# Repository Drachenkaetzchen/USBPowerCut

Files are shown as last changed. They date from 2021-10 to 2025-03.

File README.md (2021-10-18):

# USB Power Cut

A small PCB to control power to a USB device. I've designed this in order to be able to cut power to a
[HDMI display](https://www.aliexpress.com/item/32889893278.html) when it's not in use, for example, via a Raspberry Pi.

# Specifications

- MicroUSB input
- USB Type A output
- Maximum permissible USB current draw: 1A
- JST XH to control the power. Control voltage 3.3V or 5V.
- Active power consumption 35mA (only when switched on)
- USB data lines are passed through

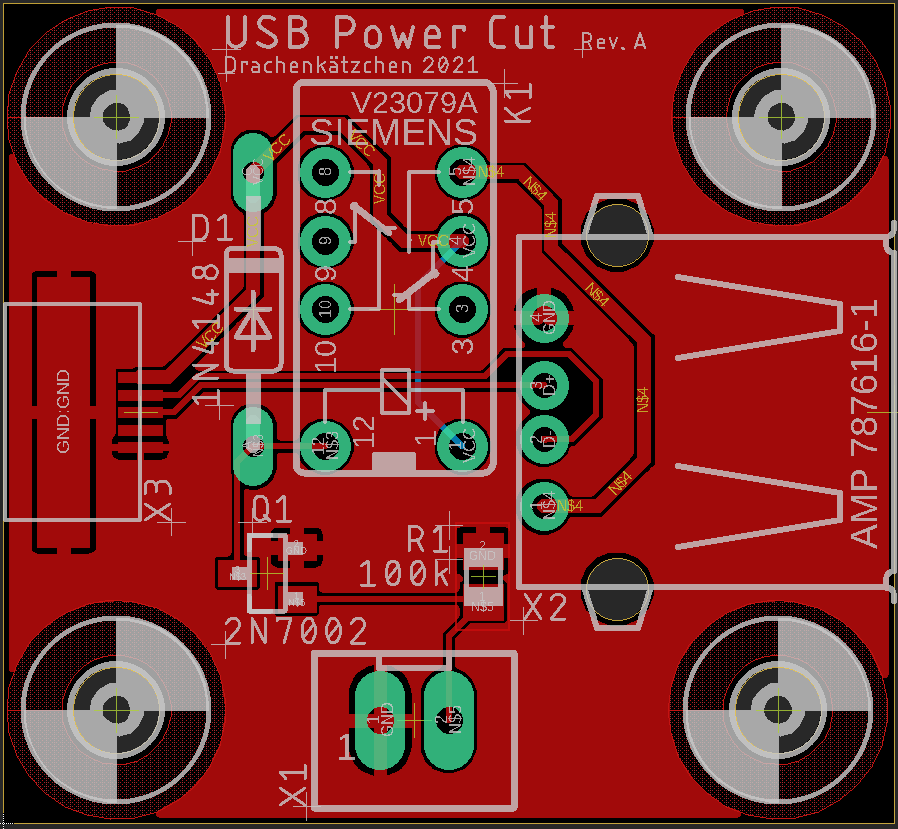
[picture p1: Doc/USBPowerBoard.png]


# Known Issues

- One mounting hole is offset to the right by 0.5mm, the DIN mounting adapter is adjusted for that.

# BOM

| Designator| Part
| ---|---
| D1 | 1N4148 DO35-10 
| K1 | V23079-A1011-B301 
| Q1 | 2N7002 SOT23 
| R1 | 100k 0805 
| X1 | JST XH 2 pin
| X2 | AMP 787616-1 
| X3 | 10104110-0001LF 

# FAQ

**Why a relay?**

I didn't have any P-channel mosfets in stock, but plenty of those small relays, so that's why I based my design around
them. I rather use components I have in stock than to order new ones.

N-channel mosfets shouldn't be used to control USB power due to possible leakage over the data lines.

**Why not use the RPI4 USB power control functionality?**

On a Raspberry Pi 4, this cuts power to all USB ports. In my case, I only want the display to be turned off. All other
ports should remain on.

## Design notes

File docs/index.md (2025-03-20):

# USB Power Cut Beta 2

A small device which can disconnect power to an attached USB device. The data pins are connected permanently.

## Example use cases
- Disconnect the Beacon surface scanner if not in use
- Turn off a screen powered by USB

## Usage
- Connect GND to any V-/GND point on your mainboard (NOT Fan-, that is not GND/V- but a switched GND!)
- Connect CTL to any pin that can pull CTL low, examples:
  - Fan- on any fan output
  - GPIO pins which are directly connected to STM32 MCUs (RP2040 MCUs cannot handle direct connection, Fan- on RP2040 MCUs is fine)
  - Toggle Switch between CTL and GND 

## Technical Details
- CTL is pulled up to 5V via a 10k resistor (hence the RP2040 MCU limitation)
- Uses a dedicated USB power controller to safely switch power (AP2111SG)
- Maximum current capability: 2A

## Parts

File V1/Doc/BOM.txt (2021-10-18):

Partlist

Exported from USBPowerCut.brd at 18/10/2021 12:52

EAGLE Version 9.6.2 Copyright (c) 1988-2020 Autodesk, Inc.

Assembly variant: 

Part     Value                  Package                    Library                                        Position (mil)        Orientation

D1       1N4148                 DO35-10                    diode                                          (365 750)             R270
K1       V23079-A1011-B301      V23079A                    Siemens-Rel                                    (570 750)             R90
Q1       2N7002                 SOT23                      nxp_60_1_1                                     (385 365)             R90
R1       100k                   R0805                      rcl                                            (700 360)             R90
X1       JST-XH-02-PIN-LONG-PAD JST-XH-02-PACKAGE-LONG-PAD Rembrandt Electronics - JST XH Connectors v1-0 (600 150)             R0
X2       AMP 787616-1           USB                        con-amp                                        (1300 600)            R90
X3       10104110-0001LF        MICRO_USB                  10104110-0001LF                                (200 600)             R270

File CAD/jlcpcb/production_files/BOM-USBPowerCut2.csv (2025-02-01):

Comment | Designator | Footprint | LCSC | Quantity
Conn_01x02_Pin | J2 | JST_PH_B2B-PH-K_1x02_P2.00mm_Vertical | C131337 | 1
100n | C1 | C_0603_1608Metric | C14663 | 1
AP2111SG-13 | IC1 | SOIC127P600X175-8N | C151559 | 1
10uF | C2 | C_0603_1608Metric | C19702 | 1
USB_A | J3 | USB_A_CONNFLY_DS1095-WNR0 | C19944603 | 1
1M | R1,R5 | R_0603_1608Metric | C22935 | 2
5.1k | R2,R3 | R_0603_1608Metric | C23186 | 2
10k | R4 | R_0603_1608Metric | C25804 | 1
USB_C_Receptacle_USB2.0_16P | J1 | USB_C_Receptacle_HRO_TYPE-C-31-M-12 | C2988369 | 1

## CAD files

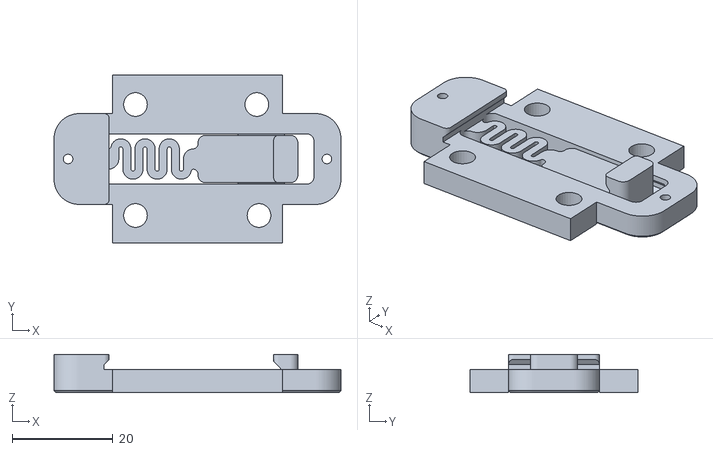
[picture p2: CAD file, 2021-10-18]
V1/STLs/USBPowerBoard.stl
56.9 x 33.4 x 7.60

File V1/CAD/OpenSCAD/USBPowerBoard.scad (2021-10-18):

$fn=30;

holeDiameter = 4.7;
holeDistance = 23;
holeBorder = 6;

holes=[
    [4.2,4.2],
    [4.2,26.2],
    [28.259,26.2],
    [28.702,4.2]
    ];


module main () {
translate([-99.2 - 56.9/2,-109.3,0]) {
import("pcb_din_clip_x3.stl");
}

cubeWidth = holeDistance + holeDiameter + holeBorder;
cubeHeight = holeDiameter + holeBorder-3;

translate([-cubeWidth/2,-cubeHeight,0]) {
cube([cubeWidth,cubeHeight,4.6]);
}
translate([-cubeWidth/2,-cubeHeight+19.7+holeBorder,0]) {
cube([cubeWidth,cubeHeight,4.6]);
}
}


module holes () {

    

translate([-16.5,-6.4,0]) {
rotate([0,0,0]) {
for (a = [ 0 : len(holes) - 1 ]) 
{
    translate([holes[a][0],holes[a][1],0]) {
    cylinder(d=holeDiameter,h=5);
    }
}
}
}
}

difference() {
    main();
    holes();
}

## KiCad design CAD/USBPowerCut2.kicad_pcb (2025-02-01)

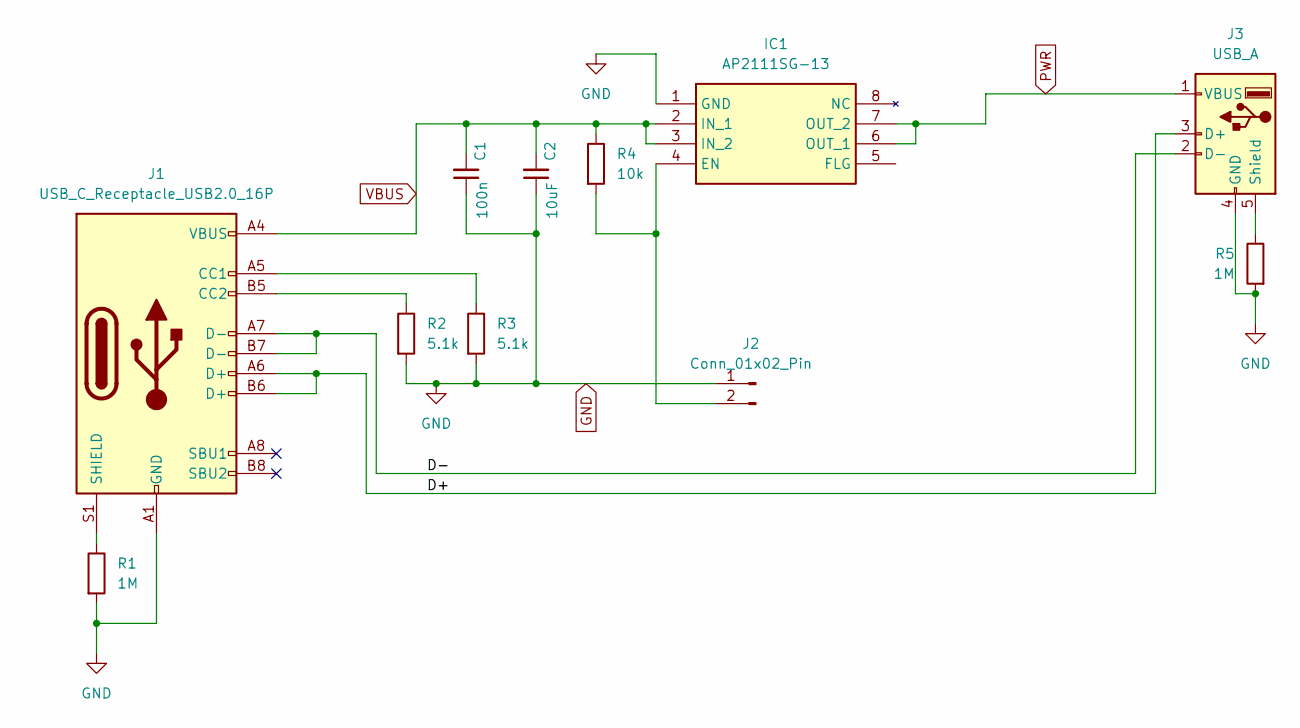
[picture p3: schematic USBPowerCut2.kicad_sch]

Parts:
C1: 100n; C_0603_1608Metric; LCSC C14663
C2: 10uF; C_0603_1608Metric; LCSC C19702
IC1: AP2111SG-13; SOIC127P600X175-8N; Manufacturer_Part_Number AP2111SG-13; Mouser Part Number 621-AP2111SG-13
J1: USB_C_Receptacle_USB2.0_16P; USB_C_Receptacle_HRO_TYPE-C-31-M-12; LCSC C2988369
J2: Conn_01x02_Pin; JST_PH_B2B-PH-K_1x02_P2.00mm_Vertical
J3: USB_A; USB_A_CONNFLY_DS1095-WNR0; LCSC C19944603
R1, R5: 1M; R_0603_1608Metric; LCSC C22935
R2, R3: 5.1k; R_0603_1608Metric; LCSC C23186
R4: 10k; R_0603_1608Metric; LCSC C25804

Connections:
/D+: J1.A6 (D+), J1.B6 (D+), J3.3 (D+)
/D-: J1.A7 (D-), J1.B7 (D-), J3.2 (D-)
GND: C1.1, C2.1, IC1.1 (GND), J1.A1 (GND), J1.A12 (GND), J1.B1 (GND), J1.B12 (GND), J2.1, J3.4 (GND), R1.2, R2.2, R3.2, R5.2
unnamed: IC1.4 (EN), J2.2, R4.2
unnamed: J1.A5 (CC1), R3.1
unnamed: J1.B5 (CC2), R2.1
unnamed: J1.S1 (SHIELD), R1.1
unnamed: J3.5 (Shield), R5.1
PWR: IC1.6 (OUT_1), IC1.7 (OUT_2), J3.1 (VBUS)
VBUS: C1.2, C2.2, IC1.2 (IN_1), IC1.3 (IN_2), J1.A4 (VBUS), J1.A9 (VBUS), J1.B4 (VBUS), J1.B9 (VBUS), R4.1

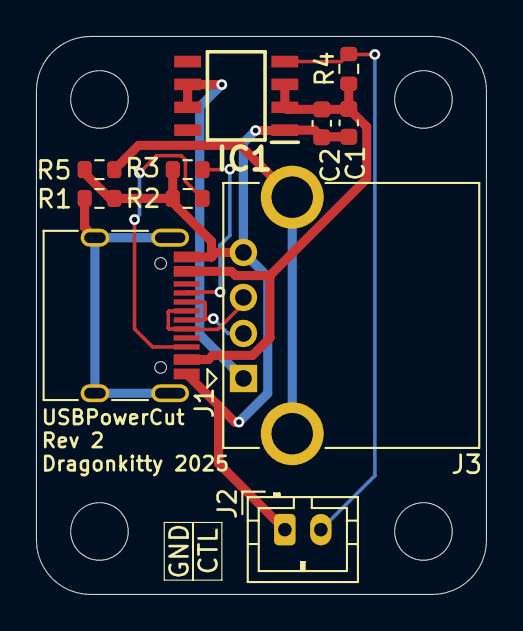
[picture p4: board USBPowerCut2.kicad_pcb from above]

Board: 2 copper layers, 25.0 x 31.0 mm, 11 parts (0 on the bottom side), 10 nets.

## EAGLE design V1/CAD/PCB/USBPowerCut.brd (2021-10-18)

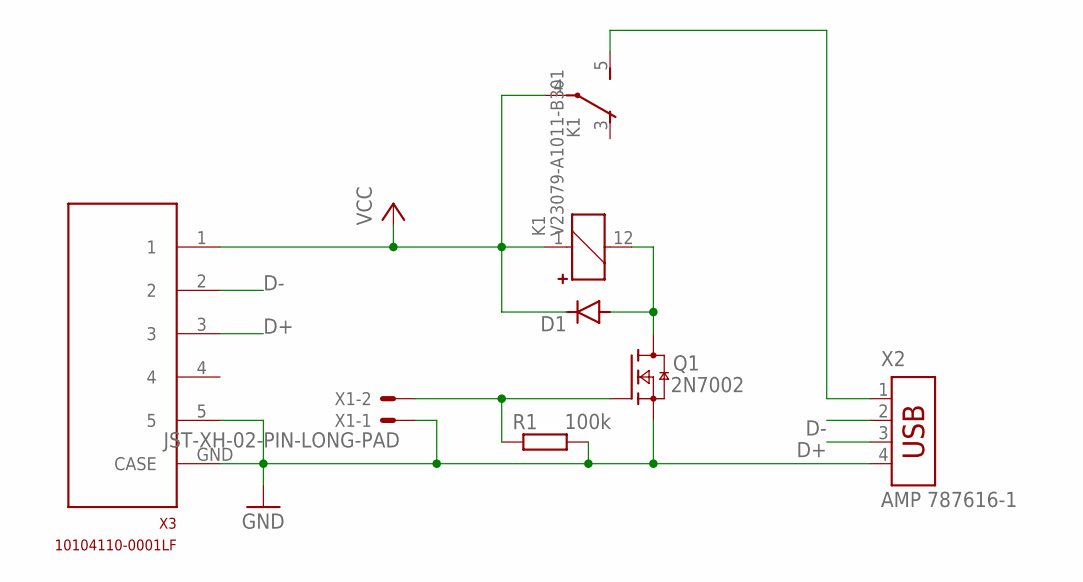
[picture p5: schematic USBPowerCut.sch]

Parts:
D1: 1N4148; DO35-10
K1: V23079-A1011-B301; V23079A
Q1: 2N7002; SOT23
R1: 100k; R0805
X1: JST-XH-02-PIN-LONG-PAD; JST-XH-02-PACKAGE-LONG-PAD
X2: AMP 787616-1; USB
X3: 10104110-0001LF; MICRO_USB

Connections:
D+: X2.3, X3.3
D-: X2.2, X3.2
GND: Q1.2 (S), R1.2, X1.1, X2.4, X3.5, X3.GND (CASE)
unnamed: D1.A, K1.12 (-), Q1.3 (D)
unnamed: K1.5 (S), X2.1
unnamed: Q1.1 (G), R1.1, X1.2
VCC: D1.C, K1.1 (+), K1.4, X3.1

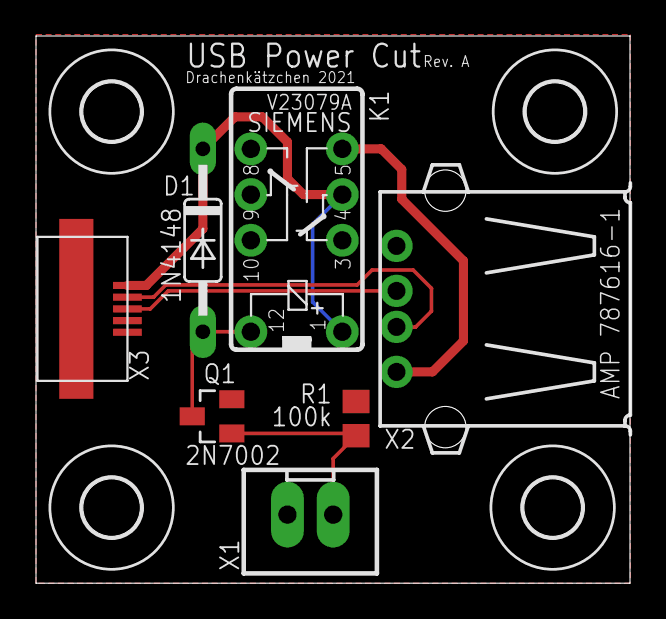
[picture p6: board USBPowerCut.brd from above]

Board: 2 copper layers, 33.0 x 30.4 mm, 11 parts (0 on the bottom side), 7 nets.

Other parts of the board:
U$1, U$2, U$3, U$4: 3,2
